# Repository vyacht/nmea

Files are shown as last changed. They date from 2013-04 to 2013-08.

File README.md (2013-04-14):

NMEA Wifi Router
====

Boards and modules for nmea wifi router. 

The files in this repository contain the schematics and boards of the 
vYacht Wifi Router. This router allows to connect directly to the NMEA 
network and distribute navigational information via Wifi or ethernet.

This router is certainly the easiest and most cost effective gateway between 
the NMEA boat on-board network and instruments and your PC or iPad/Android. All 
connections are fully isolated to avoid ground loops.

The router operates with the typical on-board 12V power supply. It has 
an efficient 12V to 3.3V step down buck converter. 

Software
====

The router runs a modified openwrt as operating system.

Availability
====

Fully assembled and professionally produced boards can be purchased via 
www.vyacht.net. 

License
====

If you are a private person you are free to use the design for any 
private use. 

NMEA Wifi Router and other designs by vyacht.net are licensed under a Creative Commons 
Attribution-NonCommercial-ShareAlike 3.0 Unported License.

The NMEA Wifi Router uses a RT3050 based Carambola as CPU and Wifi module. The Carambola 
board is unfortuntely based on a proprietary design and Ralink releases even data sheets 
only under NDA. But the Carambola board is currently the most cost effective and powerful 
Wifi and CPU solution known to me.

Version
====

Current version of this board is v8.

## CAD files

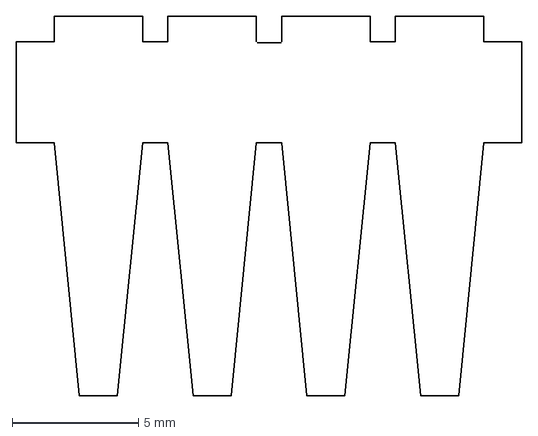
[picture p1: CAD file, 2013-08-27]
case/case-LED-guide.dxf
20.0 x 15.0 mm

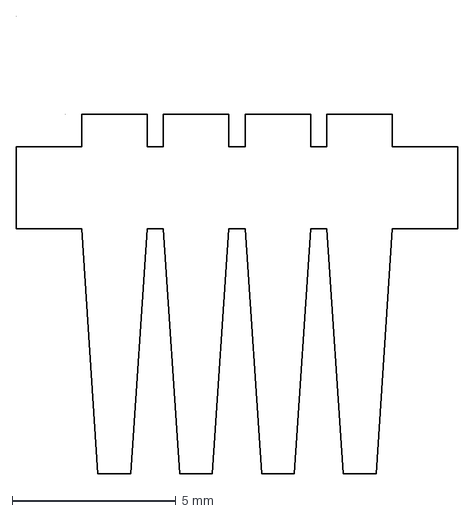
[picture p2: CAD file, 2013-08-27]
case/case-LED-guide-v2.dxf
13.5 x 14.0 mm

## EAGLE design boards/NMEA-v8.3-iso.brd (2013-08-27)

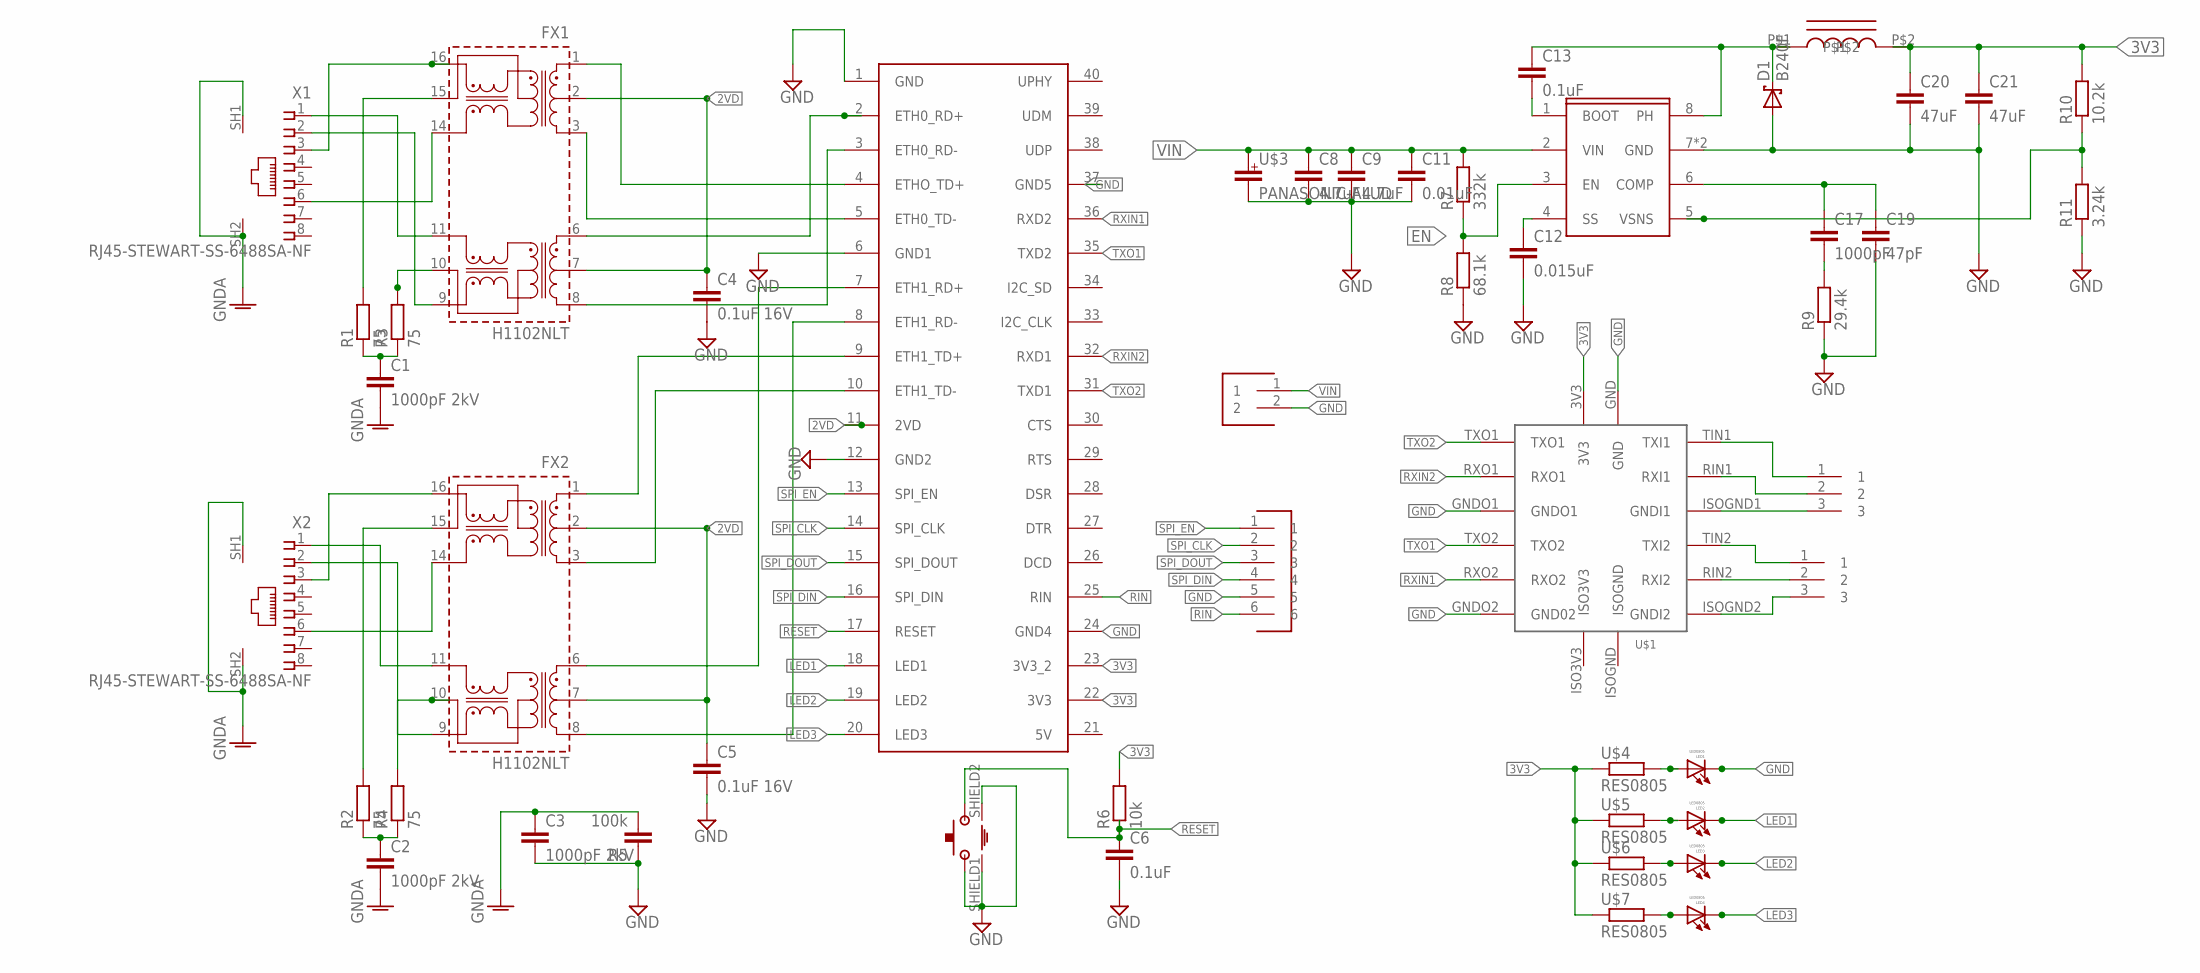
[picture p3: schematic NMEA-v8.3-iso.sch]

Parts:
C1, C2, C3: 1000pF 2kV; 1206
C4, C5: 0.1uF 16V; 0603
C6, C13: 0.1uF; 0603
C8, C9: 4.7uF; 1210
C11: 0.01uF; 0603
C12: 0.015uF; 0603
C17: 1000pF; 0603
C19: 47pF; 0603
C20, C21: 47uF; 1206
CARAMBOLA: CARAMBOLACREAM; CARAMBOLA-CREAM
D1: B240F; SMB
DATA1, DATA2: CON-3CREAM; CON-3-CREAM
FX1, FX2: H1102NLT; H/HX1XXXNL
J1: CON-5MM-2; CON--5MM-2
L1: CLF_TDK_INDUCTORCLF10040; CLF10040
LED1, LED2, LED3, LED4: LED0805; L0805
R1, R2, R3, R4: 75; 0603
R5: 100k; 1206
R6: 10k; 0603
R7: 332k; 0603
R8: 68.1k; 0603
R9: 29.4k; 0603
R10: 10.2k; 0603
R11: 3.24k; 0603
U8: TPS54231; SOIC-THERMAL
U$1: ISO-BOARDV1; ISO-BOARD
U$2: TACTILE-SWITCH-FSMRA1J
U$3: PANASONIC-ALUD; PANASONIC_D
U$4, U$5, U$6, U$7: RES0805; 0603
U$8: CON-6
X1, X2: RJ45-STEWART-SS-6488SA-NF; RJ45-STEWART-6488

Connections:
2VD: C4.1, C5.1, CARAMBOLA.11 (2VD), FX1.2, FX1.7, FX2.2, FX2.7
3V3: C20.1, C21.1, CARAMBOLA.22 (3V3), CARAMBOLA.23 (3V3_2), L1.P$2, R6.2, R10.2, U$1.3V3, U$4.1, U$5.1, U$6.1, U$7.1
EN: R7.1, R8.2, U8.3 (EN)
ETH1_RD-: CARAMBOLA.8 (ETH1_RD-), FX2.8
GND: C3.2, C4.2, C5.2, C6.2, C8.2, C9.2, C11.2, C12.2, C19.2, C20.2, C21.2, CARAMBOLA.1 (GND), CARAMBOLA.6 (GND1), CARAMBOLA.12 (GND2), CARAMBOLA.24 (GND4), CARAMBOLA.37 (GND5), D1.A, J1.2, LED1.C, R5.1, R8.1, R9.1, R11.1, U8.7 (GND), U8.P$1 (GND), U$1.GND, U$1.GNDO1, U$1.GNDO2 (GND02), U$2.2, U$2.SHIELD1, U$2.SHIELD2, U$3.-, U$8.5
GNDA: C1.2, C2.2, C3.1, R5.2, X1.SH1, X1.SH2, X2.SH1, X2.SH2
ISOGND1: DATA1.3, U$1.ISOGND1 (GNDI1)
ISOGND2: DATA2.3, U$1.ISOGND2 (GNDI2)
LED1: CARAMBOLA.18 (LED1), LED2.C
LED2: CARAMBOLA.19 (LED2), LED3.C
LED3: CARAMBOLA.20 (LED3), LED4.C
unnamed: CARAMBOLA.4 (ETHO_TD+), FX1.1
unnamed: C13.2, U8.1 (BOOT)
unnamed: LED1.A, U$4.2
unnamed: LED2.A, U$5.2
unnamed: LED3.A, U$6.2
unnamed: R10.1, R11.2, U8.5 (VSNS)
unnamed: C17.1, C19.1, U8.6 (COMP)
unnamed: C17.2, R9.2
unnamed: LED4.A, U$7.2
unnamed: CARAMBOLA.2 (ETH0_RD+), FX1.6
unnamed: CARAMBOLA.5 (ETH0_TD-), FX1.3
unnamed: CARAMBOLA.3 (ETH0_RD-), FX1.8
unnamed: C2.1, R2.1, R4.1
unnamed: FX1.10, R3.2
unnamed: FX1.15, R1.2
unnamed: C1.1, R1.1, R3.1
unnamed: FX1.11, X1.1
unnamed: FX1.9, X1.2
unnamed: FX1.16, X1.3
unnamed: FX1.14, X1.6
unnamed: CARAMBOLA.7 (ETH1_RD+), FX2.6
unnamed: CARAMBOLA.9 (ETH1_TD+), FX2.1
unnamed: CARAMBOLA.10 (ETH1_TD-), FX2.3
unnamed: FX2.15, R2.2
unnamed: FX2.10, R4.2
unnamed: FX2.16, X2.3
unnamed: FX2.11, X2.1
unnamed: FX2.14, X2.6
unnamed: FX2.9, X2.2
PH: C13.1, D1.C, L1.P$1, U8.8 (PH)
RESET: C6.1, CARAMBOLA.17 (RESET), R6.1, U$2.1
RIN: CARAMBOLA.25 (RIN), U$8.6
RIN1: DATA1.2, U$1.RIN1 (RXI1)
RIN2: DATA2.2, U$1.RIN2 (RXI2)
RXIN1: CARAMBOLA.36 (RXD2), U$1.RXO2
RXIN2: CARAMBOLA.32 (RXD1), U$1.RXO1
SPI_CLK: CARAMBOLA.14 (SPI_CLK), U$8.2
SPI_DIN: CARAMBOLA.16 (SPI_DIN), U$8.4
SPI_DOUT: CARAMBOLA.15 (SPI_DOUT), U$8.3
SPI_EN: CARAMBOLA.13 (SPI_EN), U$8.1
SS: C12.1, U8.4 (SS)
TIN1: DATA1.1, U$1.TIN1 (TXI1)
TIN2: DATA2.1, U$1.TIN2 (TXI2)
TXO1: CARAMBOLA.35 (TXD2), U$1.TXO2
TXO2: CARAMBOLA.31 (TXD1), U$1.TXO1
VIN: C8.1, C9.1, C11.1, J1.1, R7.2, U8.2 (VIN), U$3.+

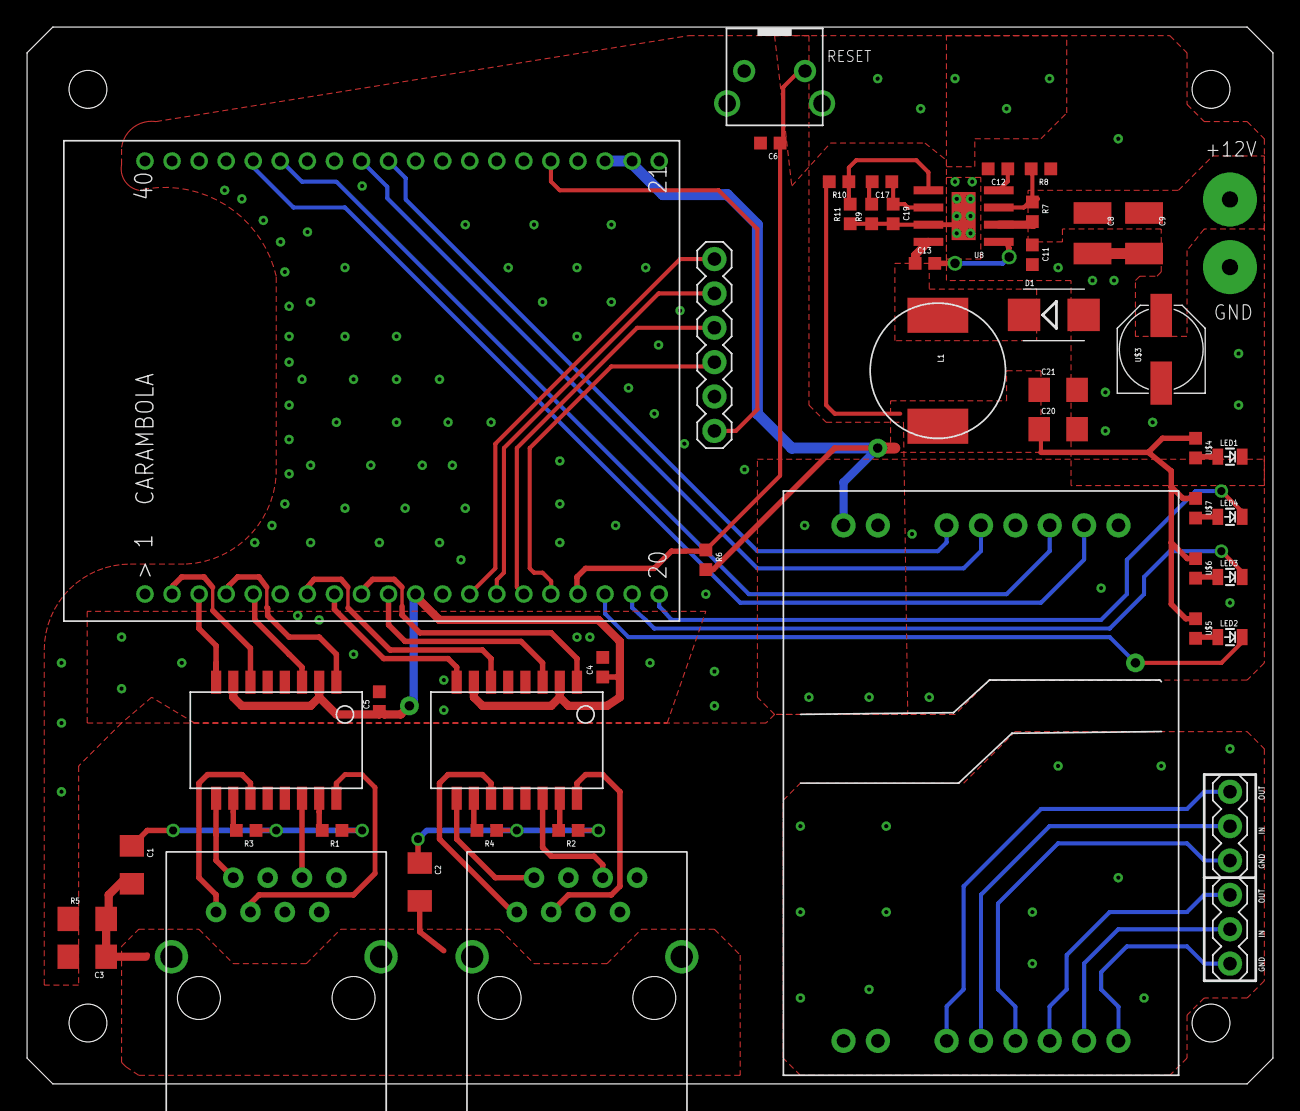
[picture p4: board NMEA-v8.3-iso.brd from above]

Board: 2 copper layers, 92.1 x 78.1 mm, 49 parts (0 on the bottom side), 57 nets.

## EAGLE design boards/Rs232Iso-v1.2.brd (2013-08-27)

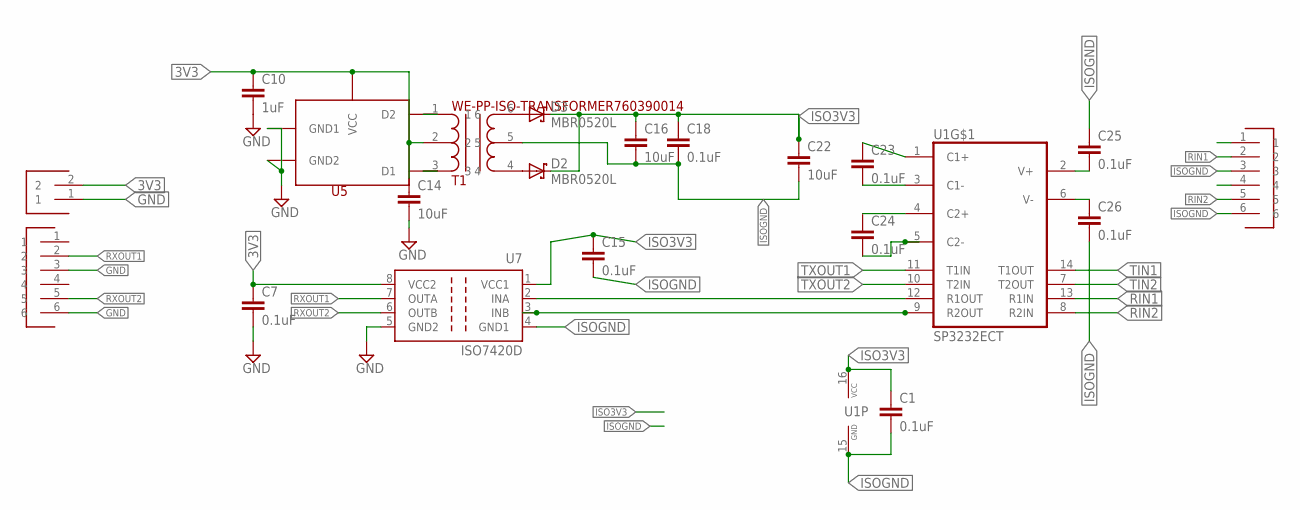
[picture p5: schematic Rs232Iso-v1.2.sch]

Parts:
C1, C7, C15, C18, C23, C24, C25, C26: 0.1uF; 0603
C10: 1uF; 0805
C14, C16, C22: 10uF; 0805
D2, D3: MBR0520L; SOD123
J1: CON-2STD-2.54; CON-2
J2, J4: CON-6
T1: WE-PP-ISO-TRANSFORMER760390014; WE_TRANSFORMER
U1: SP3232ECT; SO16
U5: SN6501DBVT; SOT23-5L
U7: ISO7420D; SO08

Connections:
3V3: C7.1, C10.1, C14.1, J1.2, T1.2, U5.2 (VCC), U7.8 (VCC2)
GND: C7.2, C10.2, C14.2, J1.1, J4.3, J4.6, U5.4 (GND1), U5.5 (GND2), U7.5 (GND2)
ISO3V3: C1.1, C15.1, C16.1, C18.1, C22.1, D2.C, D3.C, U1.16 (VCC), U7.1 (VCC1)
ISOGND: C1.2, C15.2, C16.2, C18.2, C22.2, C25.1, C26.2, J2.3, J2.6, T1.5, U1.15 (GND), U7.4 (GND1)
unnamed: D3.A, T1.6
unnamed: D2.A, T1.4
unnamed: T1.1, U5.3 (D2)
unnamed: T1.3, U5.1 (D1)
unnamed: C23.2, U1.3 (C1-)
unnamed: U1.12 (R1OUT), U7.2 (INA)
unnamed: C24.1, U1.4 (C2+)
unnamed: U1.9 (R2OUT), U7.3 (INB)
unnamed: C24.2, U1.5 (C2-)
unnamed: C23.1, U1.1 (C1+)
RIN1: J2.2, U1.13 (R1IN)
RIN2: J2.5, U1.8 (R2IN)
RXOUT1: J4.2, U7.7 (OUTA)
RXOUT2: J4.5, U7.6 (OUTB)
TIN1: U1.14 (T1OUT)
TIN2: U1.7 (T2OUT)
TXOUT1: U1.11 (T1IN)
TXOUT2: U1.10 (T2IN)
V+: C25.2, U1.2 (V+)
V-: C26.1, U1.6 (V-)

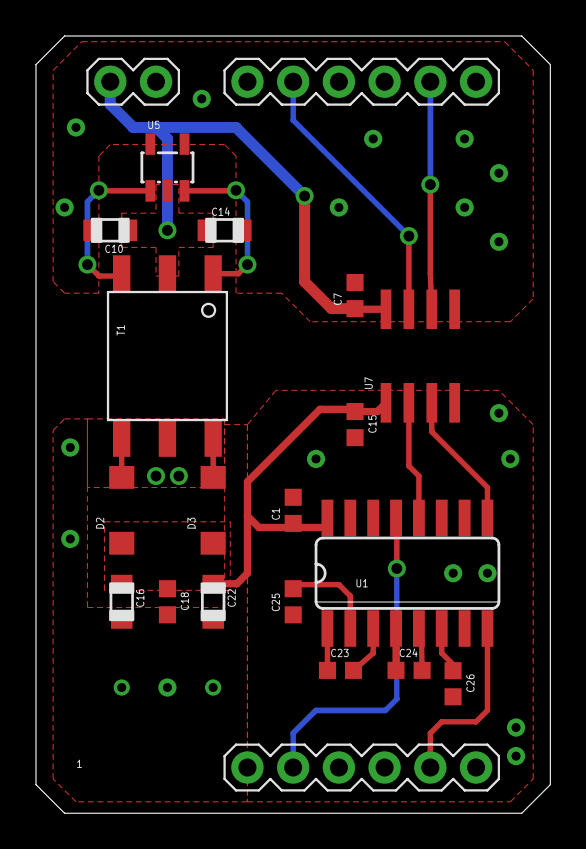
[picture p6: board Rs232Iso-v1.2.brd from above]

Board: 2 copper layers, 28.6 x 43.2 mm, 21 parts (0 on the bottom side), 20 nets.

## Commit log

2013-04-14 Bord version 8
    [NMEA-v8-iso.brd, NMEA-v8-iso.sch]
2013-04-14 adding CAN/RS232
    [CANIso.brd, CANIso.sch, Rs232Iso.brd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]
2013-04-14 remove old files
    [NMEA-v8-iso.brd, NMEA-v8-iso.sch]
2013-08-27 update working tree from custom feed
    [CANIso.brd, CANIso.sch]
2013-08-27 adding latest boards
    [NMEA-v8.1-iso.brd, NMEA-v8.1-iso.sch, NMEA-v8.2-iso.brd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]
2013-08-27 adding case files
    [NMEA-iso.brd, NMEA-iso.sch, case-LED-guide-v2.dxf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]
2013-08-27 removing board files from main dir, keeping newer in boards-dir
    [Rs232Iso.brd, Rs232Iso.sch]
